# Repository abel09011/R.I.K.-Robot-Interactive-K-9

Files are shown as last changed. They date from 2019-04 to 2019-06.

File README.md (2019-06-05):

# R.I.K.[Robot-Interactive-K-9]
Something big is built in small steps

This is the repository for R.I.K.
The goal is to collaborate between senior project members to make a quadruped dog robot autonomous. 
This project requires basic knowledge of C++, C & Java or pyhton. 

This senior project started when our group stumbled upon a youtube video showcasing an awesome robotic dog that acts on it's own named [Aibo](https://www.youtube.com/watch?v=8t8fyiiQVZ0 "Aibo"). We were intrigued by it, that we started to research how robots work. Coincidentally, this gave us the inspiration to make our own robotic dog. There was a problem, though, that this robotic dog was too expensive. We told ourselves, "There must be an easier and cheaper way!". As a result, we came up with our own design and easier to find components. 

Of course, this design is not the best, nor it is for final production, but it's intended to be a working prototype. The PCB design and 3D STL files can be found in their respective folders, along side the code. Basic knowledge of Solid Works is needed in order to Print/Laser cut the required robotic parts. The Mega micro-controller is programmed uisng the master.ino file and the android application is used to connect to robotic dog.

Figure 1 shows the current prototype
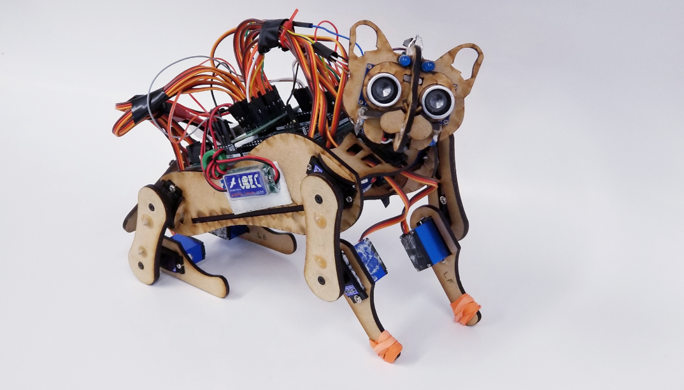
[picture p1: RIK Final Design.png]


Figure 2 shows the back of the prototype
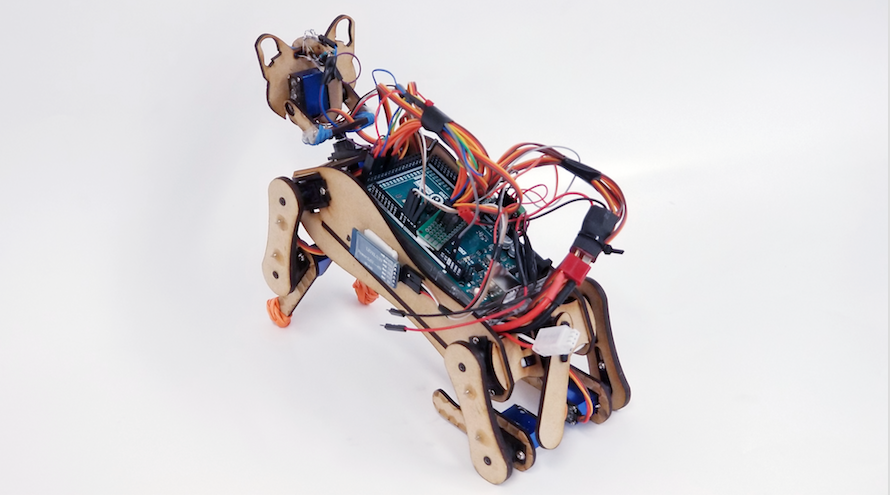
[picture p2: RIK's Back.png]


### Components

| Item | Value |
| --- | ---:|
| 1x Arduino MEGA 2560 | $40 |
| 1x USB cable A to B (also known as the printer cable) | $4 |
| 14x 13.8g MG92B Servo  ($7.70)each | $107.8  |
| 1x Breadboard | $3 |
| Various Male-to-male & Male-to-female wires | $8 |
| 1x 7.4V (2 Cell) 4000 mAh (or above) LiPo battery | $10 |
| 1x 3A UBEC (Universal Battery Elimination Circuit | $4 |
| 1x HC 06 Bluetooth module | $8 |
| 1x Protoboard | $5 |
| 1x Sodering Kit | $20 |
| Various male pin headers | $6 |
| Plywood | $10 |

### Application Functions

| Function name | Description | Voice Command |
| --- | --- | --- |
| `hey()` | **Default state** | **HEY** |
| `shake()` | **Shakes Paw** | **SHAKE** |
| `alert()` | **Listens for Commands** | |
| `up()` | **Stands Up** | **STAND** |
| `vow()` | **Bends front Legs** | **VOW** |
| `walk()` | **Does the walking Animation** | **WALK** |
| `down()` | **Bends Down** | **DOWN** |
| `tail2()` | **Tail Animation** | |
| `head2()` | **Head Animation** | |

### Voice Commands Examples

`DOWN`

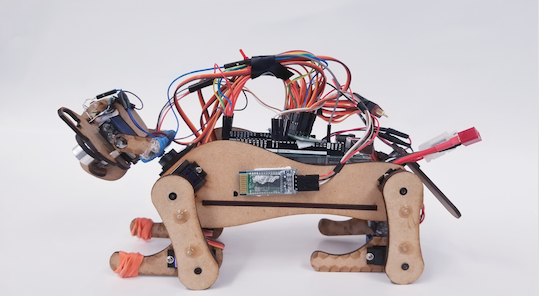
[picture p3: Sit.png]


`SHAKE`

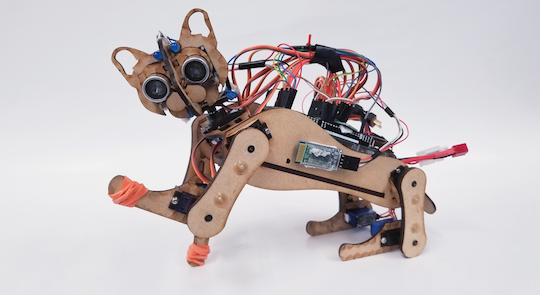
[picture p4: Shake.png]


`STAND`

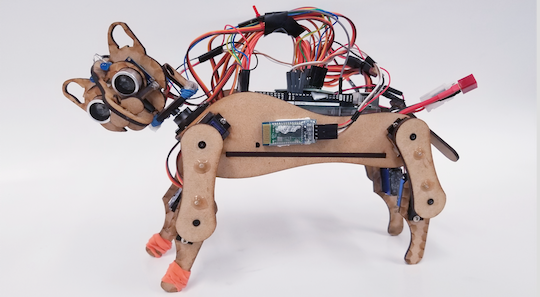
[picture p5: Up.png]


### DEMO



### 3D Model Parts

The body parts were created in SolidWorks

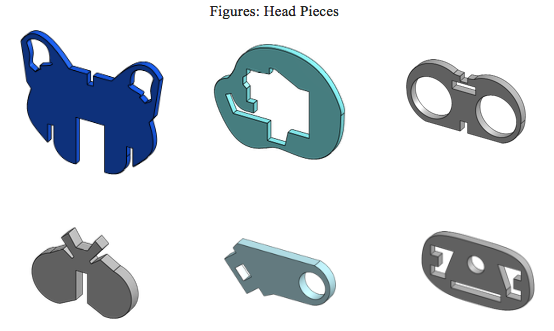
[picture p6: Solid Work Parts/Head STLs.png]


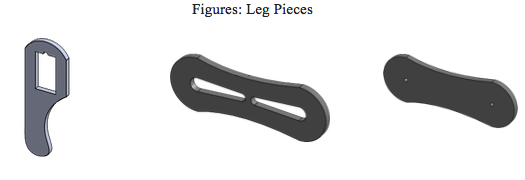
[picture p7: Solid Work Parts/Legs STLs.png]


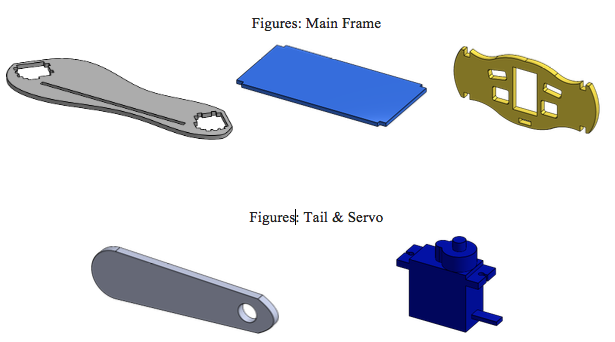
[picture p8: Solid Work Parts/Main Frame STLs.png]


The following parts were laser cutted with plywood
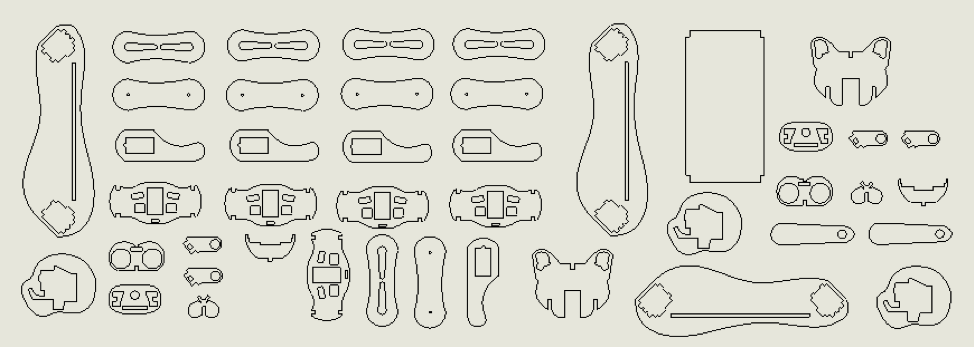
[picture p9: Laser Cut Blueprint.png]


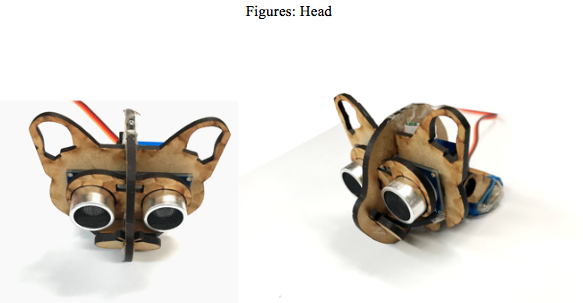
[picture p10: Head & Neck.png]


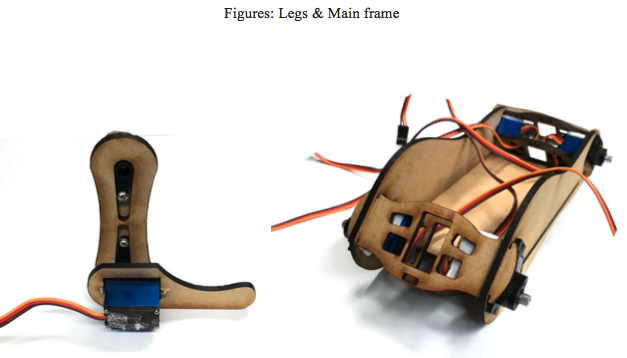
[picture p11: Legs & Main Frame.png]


### Android Application Commands

Here are the Icons and GUI for our Android application

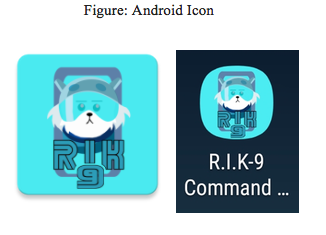
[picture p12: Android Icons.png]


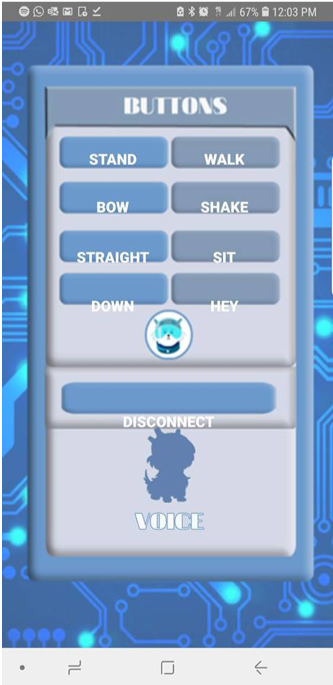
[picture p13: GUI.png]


### To Do List

- Started to document the building & programming process.

### Credits

- All the persons who contributed to the `R.I.K` project with me: Jairo Mazariegos, Paul Barrameda, Chris Espino, Franklin Cortez.
- GoogleCloudPlatform libraries, Arduino, Aibo, Petoi.

###### End

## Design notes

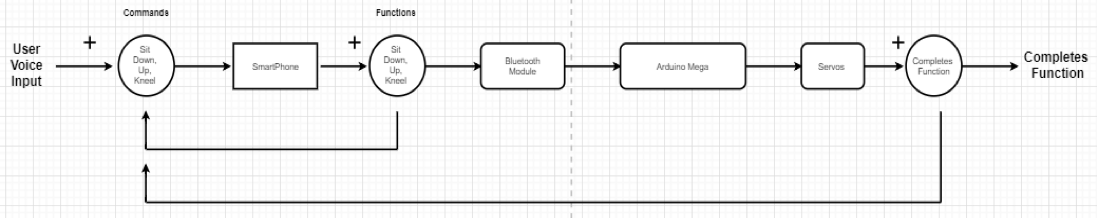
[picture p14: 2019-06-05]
Schematics/Block Diagram.png

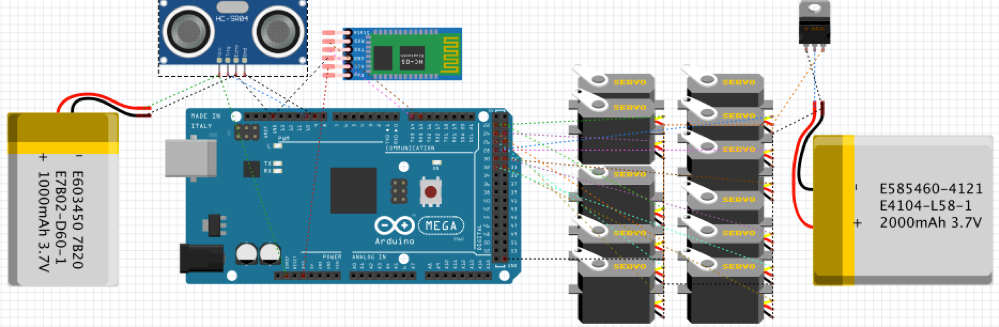
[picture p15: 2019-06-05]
Schematics/Roughtdraft.png

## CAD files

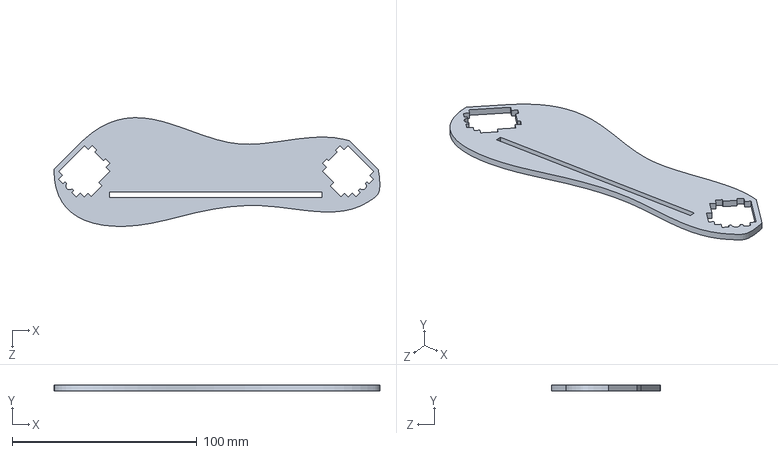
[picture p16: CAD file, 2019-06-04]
Solid Work Parts/Body 3.SLDPRT
176.4 x 3.00 x 58.8 mm

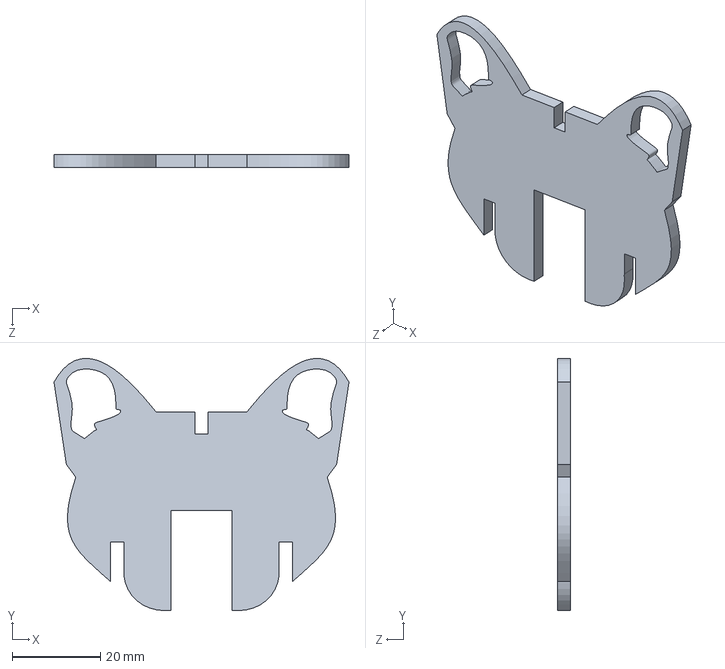
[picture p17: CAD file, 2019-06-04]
Solid Work Parts/dog face.SLDPRT
66.7 x 57.1 x 3.00 mm

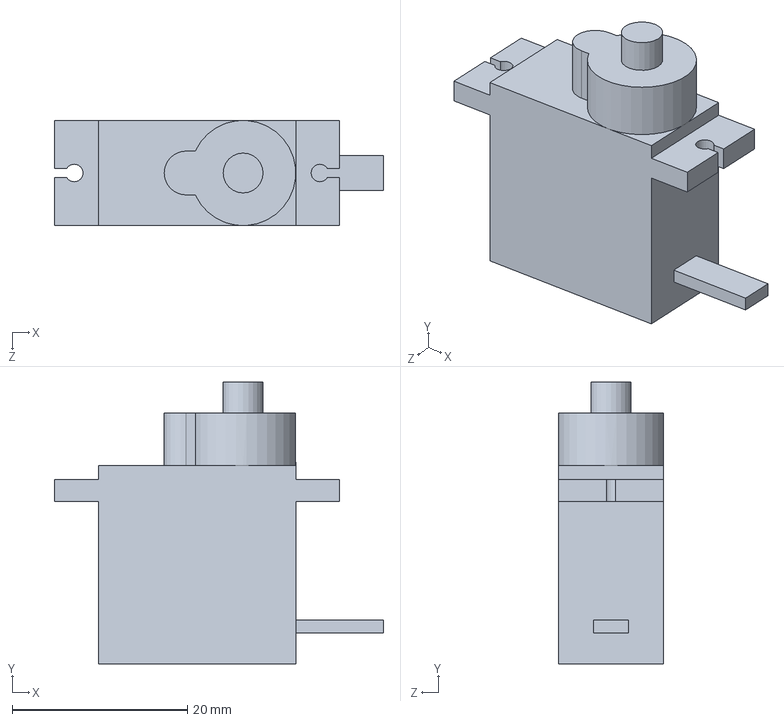
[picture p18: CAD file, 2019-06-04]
Solid Work Parts/Motor.SLDPRT
37.5 x 32.1 x 12.0 mm

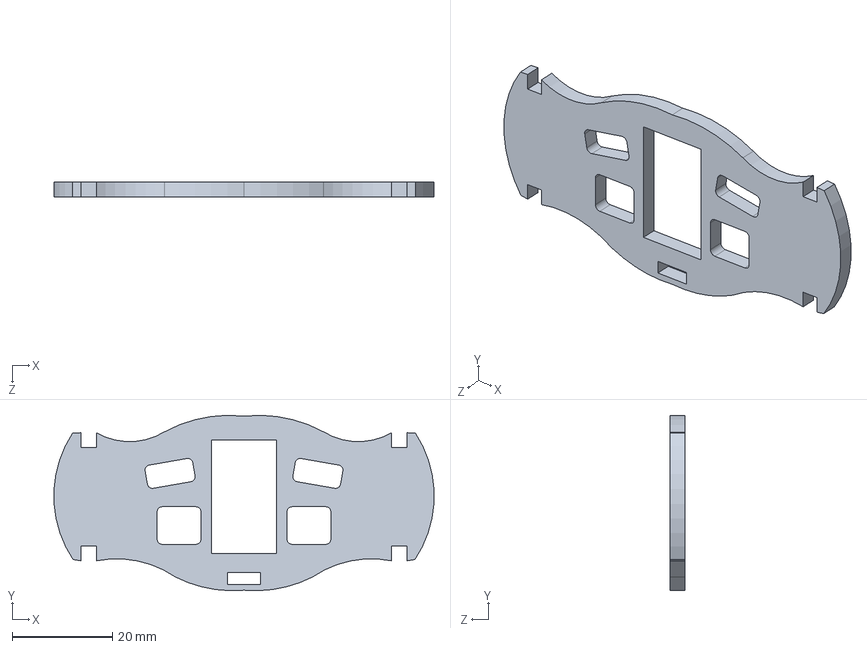
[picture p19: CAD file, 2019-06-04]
Solid Work Parts/BODY2.SLDPRT
75.9 x 35.0 x 3.00 mm

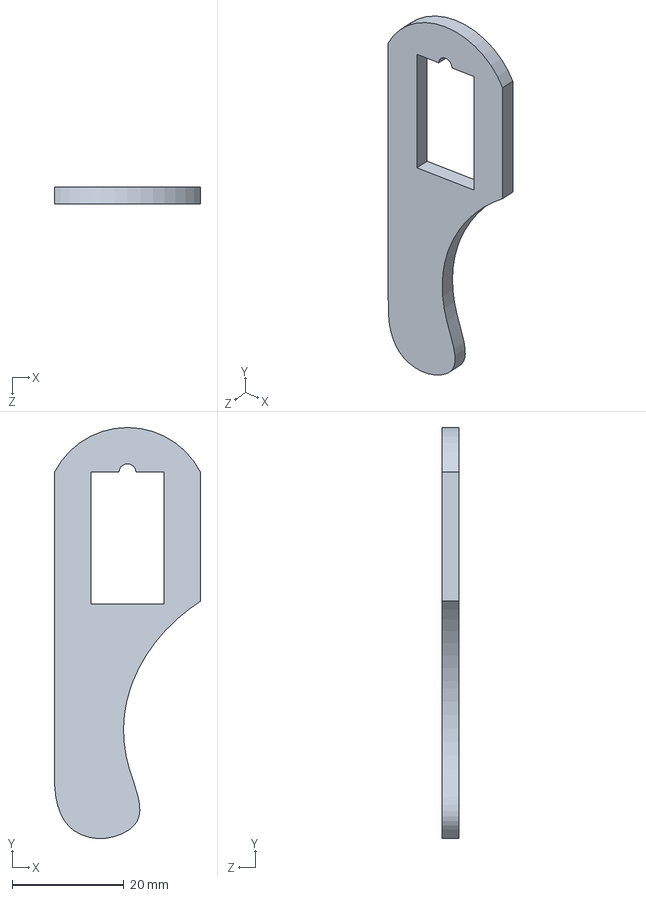
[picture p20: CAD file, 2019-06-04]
Solid Work Parts/New leg 3.SLDPRT
26.1 x 73.5 x 3.00 mm

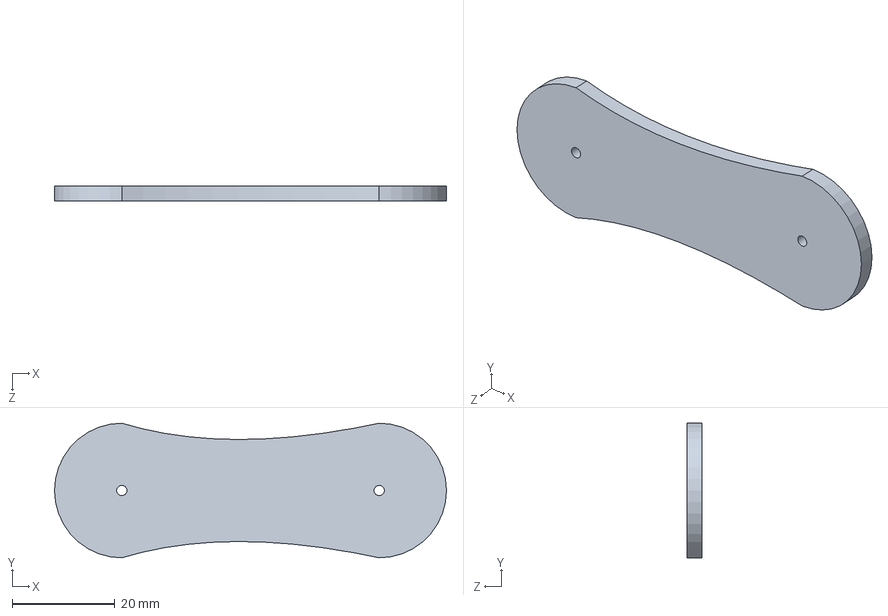
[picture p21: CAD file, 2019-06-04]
Solid Work Parts/New Leg 2.SLDPRT
76.1 x 26.1 x 3.00 mm

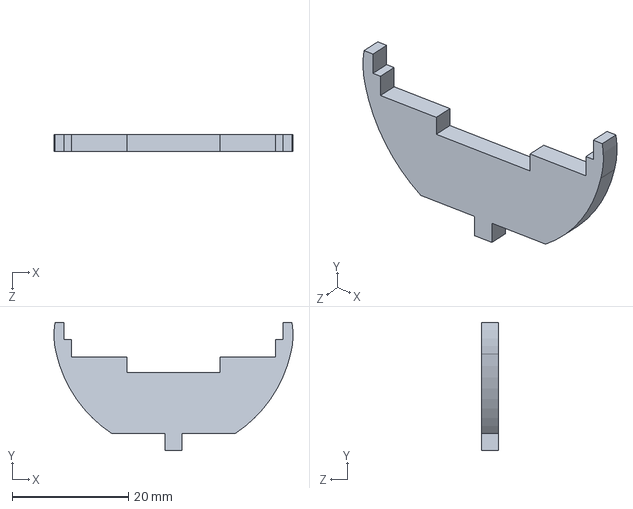
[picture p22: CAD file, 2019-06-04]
Solid Work Parts/Head 7.SLDPRT
41.1 x 22.1 x 3.00 mm

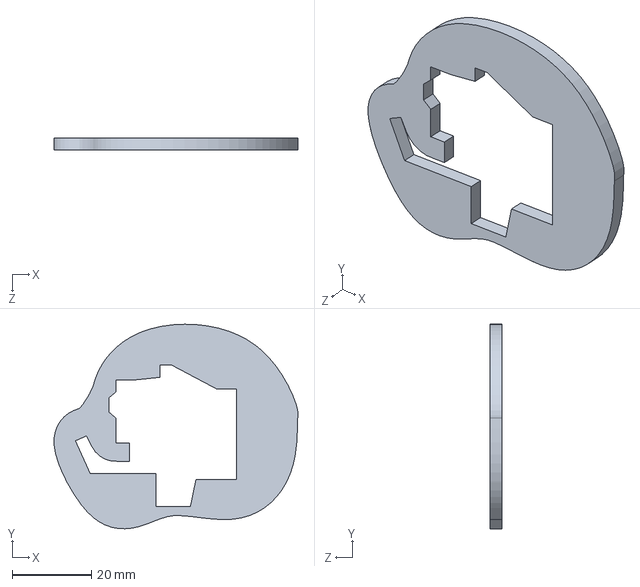
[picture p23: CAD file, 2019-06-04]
Solid Work Parts/Head 3.SLDPRT
61.6 x 51.7 x 3.00 mm

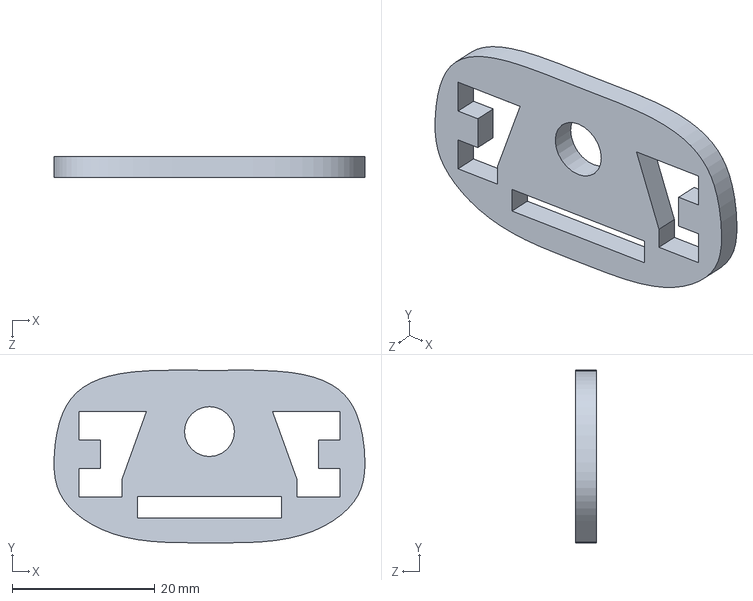
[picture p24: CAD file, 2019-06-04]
Solid Work Parts/Head 1.SLDPRT
43.6 x 24.2 x 3.00 mm

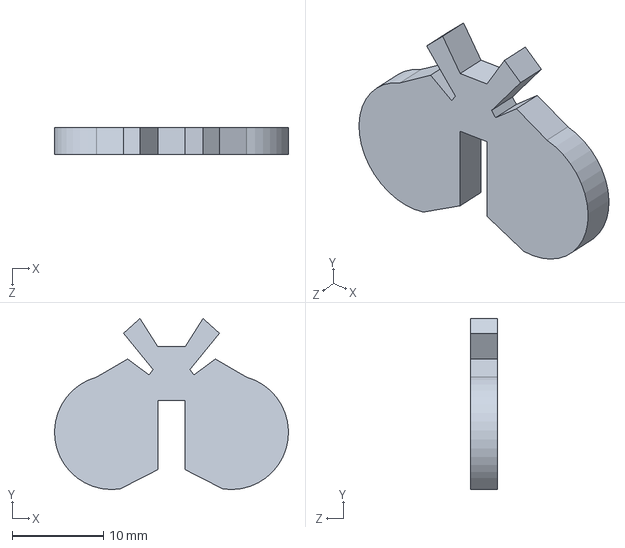
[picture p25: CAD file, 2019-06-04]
Solid Work Parts/Head 6.SLDPRT
25.7 x 18.8 x 3.00 mm

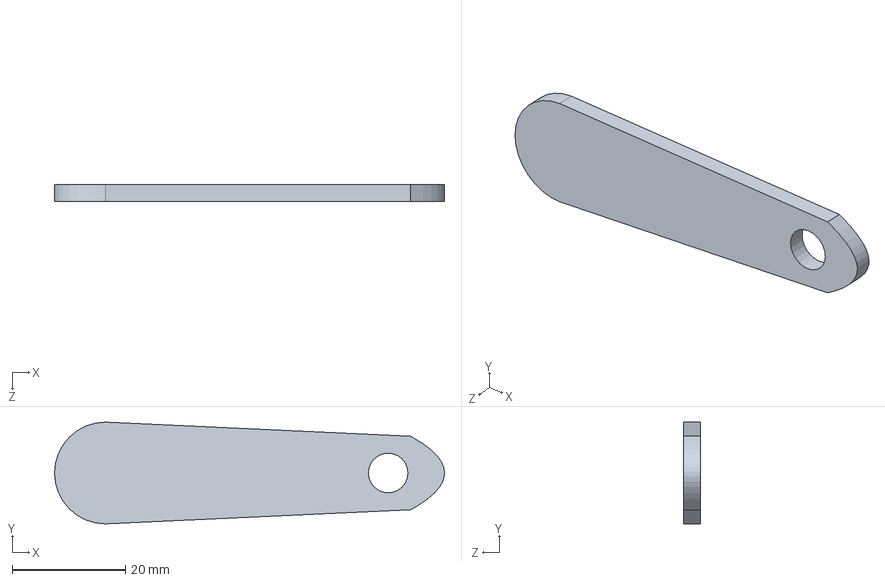
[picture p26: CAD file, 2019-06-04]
Solid Work Parts/Tail.SLDPRT
69.0 x 18.0 x 3.00 mm

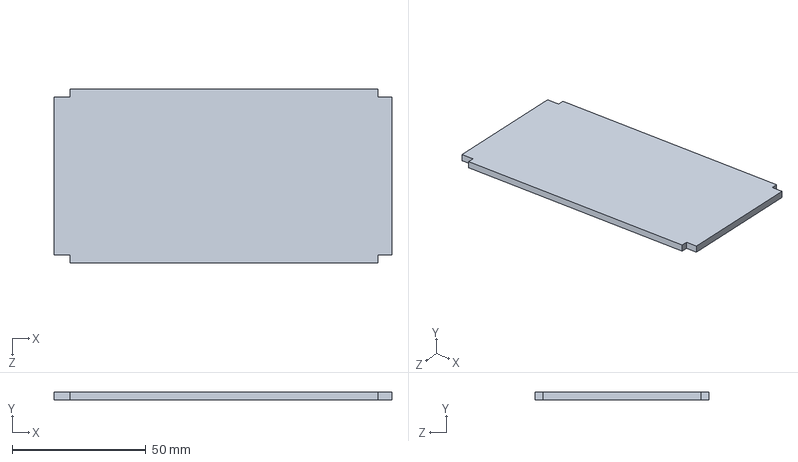
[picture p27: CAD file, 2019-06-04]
Solid Work Parts/Body 1.SLDPRT
126.2 x 3.00 x 65.0 mm

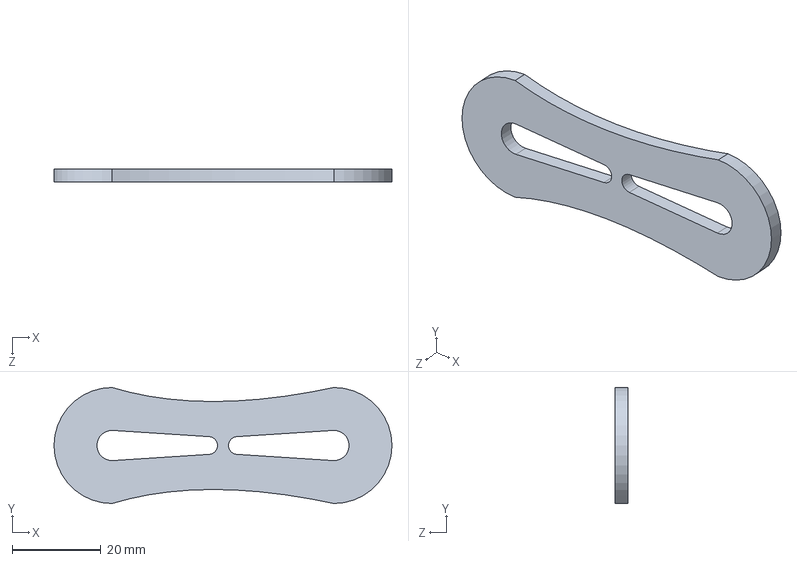
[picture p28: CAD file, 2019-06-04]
Solid Work Parts/New Leg 1.SLDPRT
76.1 x 26.1 x 3.00 mm

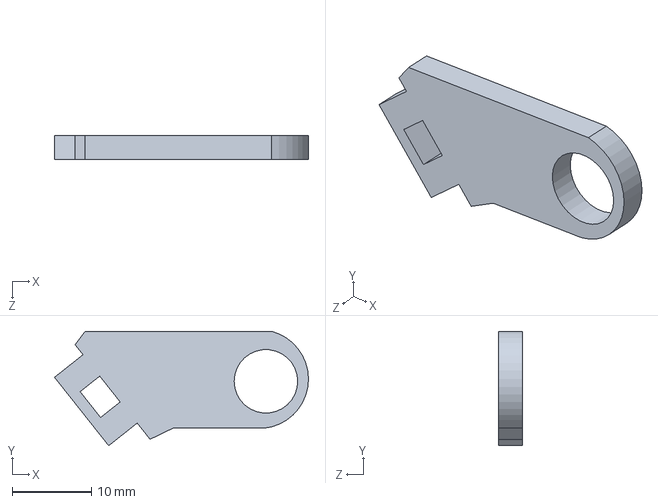
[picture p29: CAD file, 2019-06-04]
Solid Work Parts/Head 2.SLDPRT
32.0 x 14.4 x 3.00 mm

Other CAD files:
Solid Work Parts/Head 5.SLDPRT
Solid Work Parts/Laser Drawing.SLDDRW

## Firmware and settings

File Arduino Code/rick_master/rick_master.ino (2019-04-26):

#include <Servo.h>


// pin assignments
#define FRH_pin    23
#define FRK_pin    24
#define FLH_pin    26
#define FLK_pin    27

#define BRH_pin    29
#define BRK_pin    30
#define BLH_pin    32
#define BLK_pin    33

#define head_pin   22
#define neck_pin   25
#define tail_pin   31

// bluetooth Initation
char c;
String voice = "";

// servos
Servo FRH, FRK, FLH, FLK, BRH, BRK, BLH, BLK;
Servo head, neck, tail;
const int pingPin = 2; // Trigger Pin of Ultrasonic Sensor
const int echoPin = 3; // Echo Pin of Ultrasonic Sensor


//default state
void hey()
{


  alert();
  delay(1000);
  sit();
  delay(2000);
  head2();
  delay(2000);
  tail2();
  delay(1000);
  head2();
  delay(1000);
  tail2();
  delay(1000);
  down();
  delay(1000);
  tail2();
  delay(1000);
  head2();
  delay(500);
  sit();
  delay(1000);
  
}

void tail2()
{
  for(int i=0; i<181; i++)
  {
    delay(4);
    tail.write(i);
// tail.write(120);
// delay(200);
// tail.write(160);
// delay(200);
// tail.write(120);
// delay(200);
// tail.write(80);
// delay(200);
// tail.write(120);
// delay(200);
  }

}
void shake(){

sit();
delay(1000);
 head.write(30);
 FLH.write(90); //if less than 135 then it goes forward, if it is more than 135 it goes back
  for (int i = 0; i < 7; i++)
  {
    
    FLK.write(100);
    delay(200);
    FLK.write(60);
    delay(200);
    FLK.write(30);
    delay(200);
  }
FLK.write(60);
FLH.write(155);

}


void head2()
{
  for (int i = 0; i < 4; i++)
  {
    head.write(15);
    delay(150);
    neck.write(50);
    delay(150);

  }

  for (int i = 0; i < 4; i++)
  {

    head.write(55);
    delay(150);
    neck.write(130);
    delay(150);
  }
  tail.write(120);
  head.write(40);
  neck.write(90);
  delay(3000);
}

void straight()
{ //zerored values, can move either direction
  FRH.write(45); //if less than 45 then it goes back, if it is more than 45 it goes forward
  FRK.write(110); //if less than 110 then it goes forward, if it is more than 110 it goes back
  FLH.write(135); //if less than 135 then it goes forward, if it is more than 135 it goes back
  FLK.write(60); //if less than 60 then it goes back, if it is more than 60 it goes forward

  BRH.write(135); //if less than 135 then it goes backwards, if it is more than 135 it goes forward
  BRK.write(120); //if less than 125 then it goes forward, if it is more than 125 it goes backward
  BLH.write(45); //if less than 45 then it goes forward, if it is more than 45 it goes backward
  BLK.write(65); //if less than 60 then it goes backwards, if it is more than 60 it goes forward
}

void sit()
{
  FRH.write(25); //if less than 45 then it goes back, if it is more than 45 it goes forward
  FRK.write(110); //if less than 110 then it goes forward, if it is more than 110 it goes back
  FLH.write(155); //if less than 135 then it goes forward, if it is more than 135 it goes back
  FLK.write(60); //if less than 60 then it goes back, if it is more than 60 it goes forward

  BRH.write(90); //if less than 135 then it goes backwards, if it is more than 135 it goes forward
  BRK.write(0+11); //if less than 125 then it goes forward, if it is more than 125 it goes backward
  BLH.write(90); //if less than 45 then it goes forward, if it is more than 45 it goes backward
  BLK.write(170); //if less than 60 then it goes backwards, if it is more than 60 it goes forward
}

void alert()
{ //zerored values, can move either direction
  FRH.write(45 - 20); //if less than 45 then it goes back, if it is more than 45 it goes forward
  FRK.write(110 - 35); //if less than 110 then it goes forward, if it is more than 110 it goes back
  FLH.write(135 + 20); //if less than 135 then it goes forward, if it is more than 135 it goes back
  FLK.write(60 + 45); //if less than 60 then it goes back, if it is more than 60 it goes forward

  BRH.write(135 - 20); //if less than 135 then it goes backwards, if it is more than 135 it goes forward
  BRK.write(120 - 60); //if less than 125 then it goes forward, if it is more than 125 it goes backward
  BLH.write(45 + 20); //if less than 45 then it goes forward, if it is more than 45 it goes backward
  BLK.write(65 + 50); //if less than 60 then it goes backwards, if it is more than 60 it goes forward
}

void up()
{
  BRK.write(120);
  BLK.write(65);

  delay(500);

  BRH.write(135);
  BLH.write(45);

  delay(200);

  FRK.write(110);
  FLK.write(60);

  delay(500);

  FRH.write(45);
  FLH.write(135);
}

void vow()
{
  FRH.write(20); //if less than 45 then it goes back, if it is more than 45 it goes forward
  FRK.write(20); //if less than 110 then it goes forward, if it is more than 110 it goes back

  //delay(500);

  FLH.write(160); //if less than 135 then it goes forward, if it is more than 135 it goes back
  FLK.write(160); //if less than 60 then it goes back, if it is more than 60 it goes forward

  BRH.write(135); //if less than 135 then it goes backwards, if it is more than 135 it goes forward
  BRK.write(120); //if less than 125 then it goes forward, if it is more than 125 it goes backward

  BLH.write(45); //if less than 45 then it goes forward, if it is more than 45 it goes backward
  BLK.write(65); //if less than 60 then it goes backwards, if it is more than 60 it goes forward
  //tail.write(90-90);
}

void walk(int steps)
{
  head.write(30);

  for (int i = 0; i < steps; i++)
  {
    /* first part of walking animation */
    FRH.write(70); //if less than 45 then it goes back, if it is more than 45 it goes forward
    FRK.write(150); //if less than 110 then it goes forward, if it is more than 110 it goes back

    BRH.write(90); //if less than 135 then it goes backwards, if it is more than 135 it goes forward
    BRK.write(80); //if less than 125 then it goes forward, if it is more than 125 it goes backward

    BLH.write(15); //if less than 45 then it goes forward, if it is more than 45 it goes backward
    BLK.write(20); //if less than 60 then it goes backwards, if it is more than 60 it goes forward

    FLH.write(170); //if less than 135 then it goes forward, if it is more than 135 it goes back
    FLK.write(95); //if less than 60 then it goes back, if it is more than 60 it goes forward

    delay(300);

    /* second part of walking animation */
    FRH.write(15); //if less than 45 then it goes back, if it is more than 45 it goes forward
    FRK.write(90); //if less than 125 then it goes forward, if it is more than 125 it goes backward

    BRH.write(155); //if less than 135 then it goes backwards, if it is more than 135 it goes forward
    BRK.write(145);//if less than 125 then it goes forward, if it is more than 125 it goes backward

    BLH.write(80); //if less than 45 then it goes forward, if it is more than 45 it goes backward
    BLK.write(100); //if less than 60 then it goes backwards, if it is more than 60 it goes forward

    FLH.write(110); //if less than 135 then it goes forward, if it is more than 135 it goes back
    FLK.write(20); //if less than 60 then it goes back, if it is more than 60 it goes forward

    delay(300);

  }
  
  //straight();
  alert();
}

void down()
{
  BRH.write(100); //if less than 135 then it goes backwards, if it is more than 135 it goes forward
  BRK.write(0); //if less than 125 then it goes forward, if it is more than 125 it goes backward

  BLH.write(80); //if less than 45 then it goes forward, if it is more than 45 it goes backward
  BLK.write(180); //if less than 60 then it goes backwards, if it is more than 60 it goes forward

  delay(500);

  FRH.write(10); //if less than 45 then it goes back, if it is more than 45 it goes forward
  FRK.write(10); //if less than 110 then it goes forward, if it is more than 110 it goes back

  FLH.write(170); //if less than 135 then it goes forward, if it is more than 135 it goes back
  FLK.write(160); //if less than 60 then it goes back, if it is more than 60 it goes forward
}


//Sets up the pin to the servos
void setup()
{
  FRH.attach(FRH_pin);
  FRK.attach(FRK_pin);
  FLH.attach(FLH_pin);
  FLK.attach(FLK_pin);

  BRH.attach(BRH_pin);
  BRK.attach(BRK_pin);
  BLH.attach(BLH_pin);
  BLK.attach(BLK_pin);

  neck.attach(neck_pin);
  head.attach(head_pin);
  tail.attach(tail_pin);

  Serial.begin(9600);
  
  /////////////////
  //1st stage on default
  ////////////////
  sit();
  head2();
  delay(2000); 
  tail2();
  delay(5000);
  head2();
  delay(1000);
  neck.write(120);
  delay(500);
  neck.write(170);
  delay(2000);
  neck.write(90);
  delay(1000);
  neck.write(0);
  delay(2000);
  head2();
//  /////////////////
//  //2nd stage on default
//  ////////////////
  delay(1000);
  neck.write(120);
  delay(500);
  neck.write(170);
  delay(2000);
  neck.write(70);
  delay(1000);
  neck.write(0);
  delay(2000);
  head2();
  delay(4000);
  ////////////////
  //3rd stage on default
  ////////////////
  delay(1000);
  neck.write(150);
  delay(500);
  neck.write(120);
  delay(2000);
  neck.write(50);
  delay(1000);
  neck.write(50);
  delay(2000);
  head2();
  delay(500);
  tail.write(150);
  delay(2000);
  down();
  ///////////////
  //4th stage on default
  ////////////////
  delay(2000);
  neck.write(60);
  delay(500);
  neck.write(30);
  delay(2000);
  neck.write(90);
  delay(1000);
  neck.write(180);
  delay(2000);
  head2();
  delay(1000);
  sit();
  ///////////////
  //5th stage on default
  ////////////////
  delay(1000);
  neck.write(130);
  delay(500);
  tail.write(0);
  delay(1000);
  tail.write(170);
  delay(2000);
  neck.write(170);
  delay(2000);
  neck.write(90);
  delay(1000);
  neck.write(0);
  delay(2000);
  head2();
  ///////////////
  //6th stage on default
  ////////////////
  delay(1000);
  neck.write(130);
  delay(3000);
  tail.write(50);
  delay(1000);
  tail.write(120);
  delay(2000);
  neck.write(170);
  delay(2000);
  neck.write(40);
  delay(1000);
  neck.write(0);
  delay(2000);
  head2();
  delay(500);
  alert();
  delay(3000);
  sit();
  

  delay(2000);
  alert();
  delay(3000);
  straight();
  delay(2000);
  walk(10);
  delay(1500);
  alert();
  delay(1000);
  sit();
  delay(1000);
}

//[Reference for the bluetooth module]
//white goes to 0
//brown goes to 1


void loop() {
  while (Serial.available())
  {
    delay(10);

    c = Serial.read();
    if (c == '#') break;
    voice += c;
  }

  if (voice.length() > 0) {
    Serial.println("voice: " + voice);

    if (voice == "sit") {
      sit();
    } else if (voice == "up" || voice == "stand") {
      up();
    } else if (voice == "bow" || voice == "vow") {
      vow();
    } else if (voice == "straight") {
      straight();
    } else if (voice == "down") {
      down();
    } else if (voice == "walk") {
      down();
      delay(500);
      alert();
      delay(1000);
      for(int i=50; i<101; i++){
        delay(6);
        head.write(i);
        neck.write(i);
        }
        walk(10);
        for (int i=100; i>50; i--){
          delay(6);
          
          head.write(i);
          neck.write(i+50);
        }
      
    }
      else if (voice == "hey") {
      hey();
    }
      else if (voice == "shake" || voice == "Shake") {
      shake();
    }
      else if (voice == "alert" || voice == "Alert") {
      alert();
    }
    delay(2000);
    voice = "";
  }

}

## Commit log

2019-06-04 Updated STL files
    [BODY2.SLDPRT, Body 1.SLDPRT, Body 3.SLDPRT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]
2019-06-04 Laser cut Parts
2019-06-04 STL Pictures
2019-06-04 Assembled Parts
